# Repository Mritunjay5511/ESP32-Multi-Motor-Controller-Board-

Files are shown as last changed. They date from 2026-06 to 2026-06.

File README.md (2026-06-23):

# ESP32-Multi-Motor-Controller-Board-
Custom ESP32-WROOM-32 robotics controller PCB with onboard buck/LDO power regulation, auto-program circuit, and BTS7960/RMCS/relay/servo interfaces. Designed in KiCad.
# ESP32 Dual BTS7960 Motor Driver Breakout Board

A custom 2-layer PCB designed to handle heavy-duty robotics applications. It acts as a central control board breaking out an ESP32 to interface with dual BTS7960 motor drivers, an RMCS driver, and features onboard power regulation.

## Features
- **Microcontroller:** ESP32-WROOM-32
- **Power Stage:** LM2596 Buck Regulator (12v to 5v switching) & AMS1117-3.3 (5v to 3.3v switching)
- **Motor Control Interfaces:** 2x BTS7960 H-Bridge Drivers, 1x RMCS Driver interface
- **Peripherals:** Integrated Micro USB for programming (CH340C), Boot & Reset tactile switches, and broken-out GPIO headers.

## Design Highlights
- Optimized high-frequency switching loops for the buck regulator to minimize EMI.
- Completely isolated RF antenna keepout zone on both layers for maximum wireless signal integrity.
- Solid ground planes on both layers for optimal return paths.





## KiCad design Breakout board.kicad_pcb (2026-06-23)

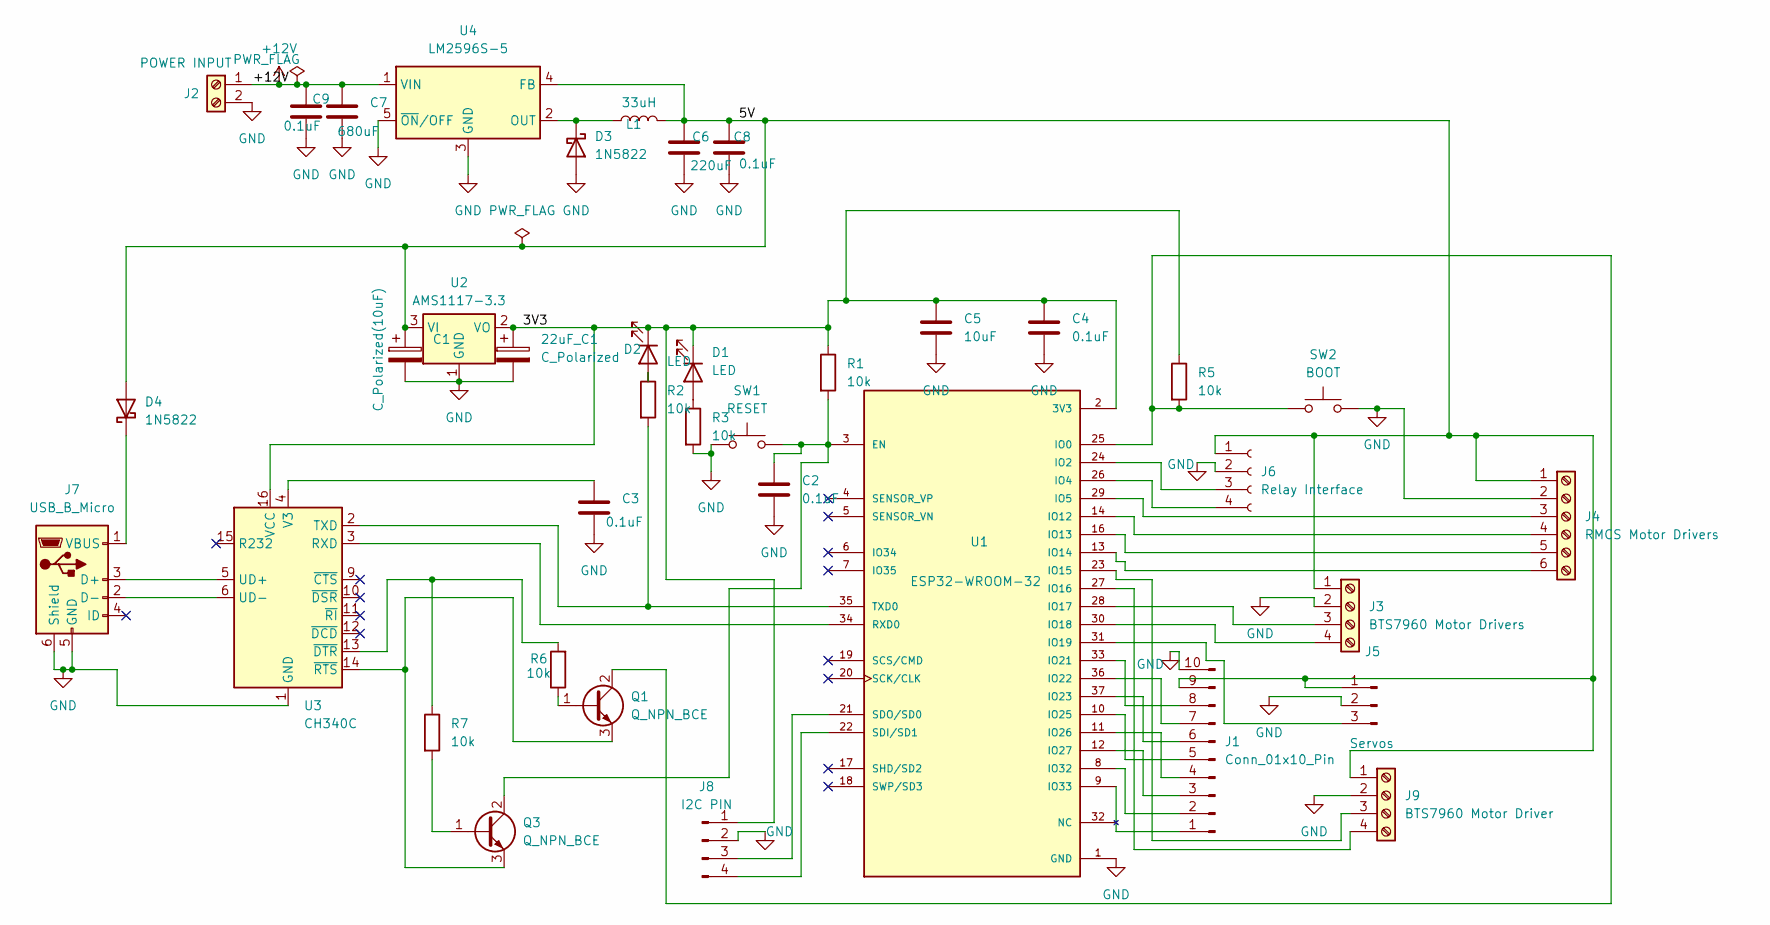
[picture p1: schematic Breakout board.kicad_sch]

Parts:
22uF_C1: C_Polarized; CP_Elec_4x5.4
C1: C_Polarized(10uF); CP_Elec_4x5.4
C2, C3, C4, C8, C9: 0.1uF; C_1206_3216Metric
C5: 10uF; C_1206_3216Metric
C6: 220uF; C_1206_3216Metric
C7: 680uF; C_1206_3216Metric
D1, D2: LED; LED_1206_3216Metric
D3: 1N5822; D_DO-201AD_P12.70mm_Horizontal
D4: 1N5822; D_DO-201AD_P15.24mm_Horizontal
J1: Conn_01x10_Pin; PinHeader_1x10_P2.54mm_Vertical
J2: POWER INPUT; TerminalBlock_Phoenix_MKDS-1,5-2-5.08_1x02_P5.08mm_Horizont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
J3: BTS7960 Motor Drivers; TerminalBlock_Phoenix_MKDS-1,5-4-5.08_1x04_P5.08mm_Horizont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
J4: RMCS Motor Drivers; TerminalBlock_Phoenix_MKDS-1,5-6-5.08_1x06_P5.08mm_Horizont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
J5: Servos; PinHeader_1x03_P2.54mm_Vertical
J6: Relay Interface; PinSocket_1x04_P2.54mm_Vertical
J7: USB_B_Micro; USB_Micro-B_Molex-105017-0001
J8: I2C PIN; PinHeader_1x04_P2.54mm_Vertical
J9: BTS7960 Motor Driver; TerminalBlock_Phoenix_MKDS-1,5-4-5.08_1x04_P5.08mm_Horizont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
L1: 33uH; L_1206_3216Metric
Q1, Q3: Q_NPN_BCE; SOT-23
R1, R2, R3, R5, R6, R7: 10k; R_1206_3216Metric
SW1: RESET; SW_PUSH_6mm
SW2: BOOT; SW_PUSH_6mm
U1: ESP32-WROOM-32; MODULE_ESP32-WROOM-32; PARTREV 2.9
U2: AMS1117-3.3; SOT-223-3_TabPin2
U3: CH340C; SOIC-16_3.9x9.9mm_P1.27mm
U4: LM2596S-5; TO-263-5_TabPin3

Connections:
+12V: C7.1, C9.1, J2.1, U4.1 (VIN)
/3V3: 22uF_C1.1, C4.1, C5.1, D1.1 (K), D2.1 (K), J8.1, R1.1, R5.1, U1.2 (3V3), U2.2 (VO), U3.16 (VCC)
/5V: C1.1, C6.1, C8.1, D4.2 (A), J1.9, J3.1, J4.1, J5.1, J6.1, J9.1, L1.2, U2.3 (VI), U4.4 (FB)
GND: 22uF_C1.2, C1.2, C2.2, C3.2, C4.2, C5.2, C6.2, C7.2, C8.2, C9.2, D3.2 (A), J1.10, J2.2, J3.2, J4.2, J5.2, J6.2, J7.5 (GND), J7.6 (Shield), J8.2, J9.2, R3.2, SW1.1, SW2.2, U1.1 (GND), U1.15 (GND), U1.38 (GND), U1.39_1 (GND), U1.39_2 (GND), U1.39_3 (GND), U1.39_4 (GND), U1.39_5 (GND), U1.39_6 (GND), U1.39_7 (GND), U1.39_8 (GND), U1.39_9 (GND), U1.39_10 (GND), U1.39_11 (GND), U1.39_12 (GND), U1.39_13 (GND), U1.39_14 (GND), U1.39_15 (GND), U1.39_16 (GND), U1.39_17 (GND), U1.39_18 (GND), U1.39_19 (GND), U1.39_20 (GND), U1.39_21 (GND), U2.1 (GND), U3.1 (GND), U4.3 (GND), U4.5 (~ON/OFF)
unnamed: D1.2 (A), R3.1
unnamed: D2.2 (A), R2.1
unnamed: D3.1 (K), L1.1, U4.2 (OUT)
unnamed: D4.1 (K), J7.1 (VBUS)
unnamed: J1.1, U1.9 (IO33)
unnamed: J1.2, U1.8 (IO32)
unnamed: J1.3, U1.12 (IO27)
unnamed: J1.4, U1.11 (IO26)
unnamed: J1.5, U1.10 (IO25)
unnamed: J1.6, U1.37 (IO23)
unnamed: J1.7, U1.36 (IO22)
unnamed: J1.8, U1.33 (IO21)
unnamed: J3.3, U1.28 (IO17)
unnamed: J3.4, U1.30 (IO18)
unnamed: J4.3, U1.29 (IO5)
unnamed: J4.4, U1.14 (IO12)
unnamed: J4.5, U1.16 (IO13)
unnamed: J4.6, U1.13 (IO14)
unnamed: J5.3, U1.31 (IO19)
unnamed: J6.3, U1.24 (IO2)
unnamed: J6.4, U1.26 (IO4)
unnamed: J7.3 (D+), U3.5 (UD+)
unnamed: J7.2 (D-), U3.6 (UD-)
unnamed: J8.3, U1.21 (SDO/SD0)
unnamed: J8.4, U1.22 (SDI/SD1)
unnamed: J9.3, U1.23 (IO15)
unnamed: J9.4, U1.27 (IO16)
unnamed: Q1.1 (B), R6.1
unnamed: Q1.2 (C), R5.2, SW2.1, U1.25 (IO0)
unnamed: Q1.3 (E), Q3.3 (E), U3.14 (~RTS)
unnamed: Q3.1 (B), R7.2
unnamed: C2.1, Q3.2 (C), R1.2, SW1.2, U1.3 (EN)
unnamed: U1.34 (RXD0), U3.3 (RXD)
unnamed: R2.2, U1.35 (TXD0), U3.2 (TXD)
unnamed: C3.1, U3.4 (V3)
unnamed: R6.2, R7.1, U3.13 (~DTR)

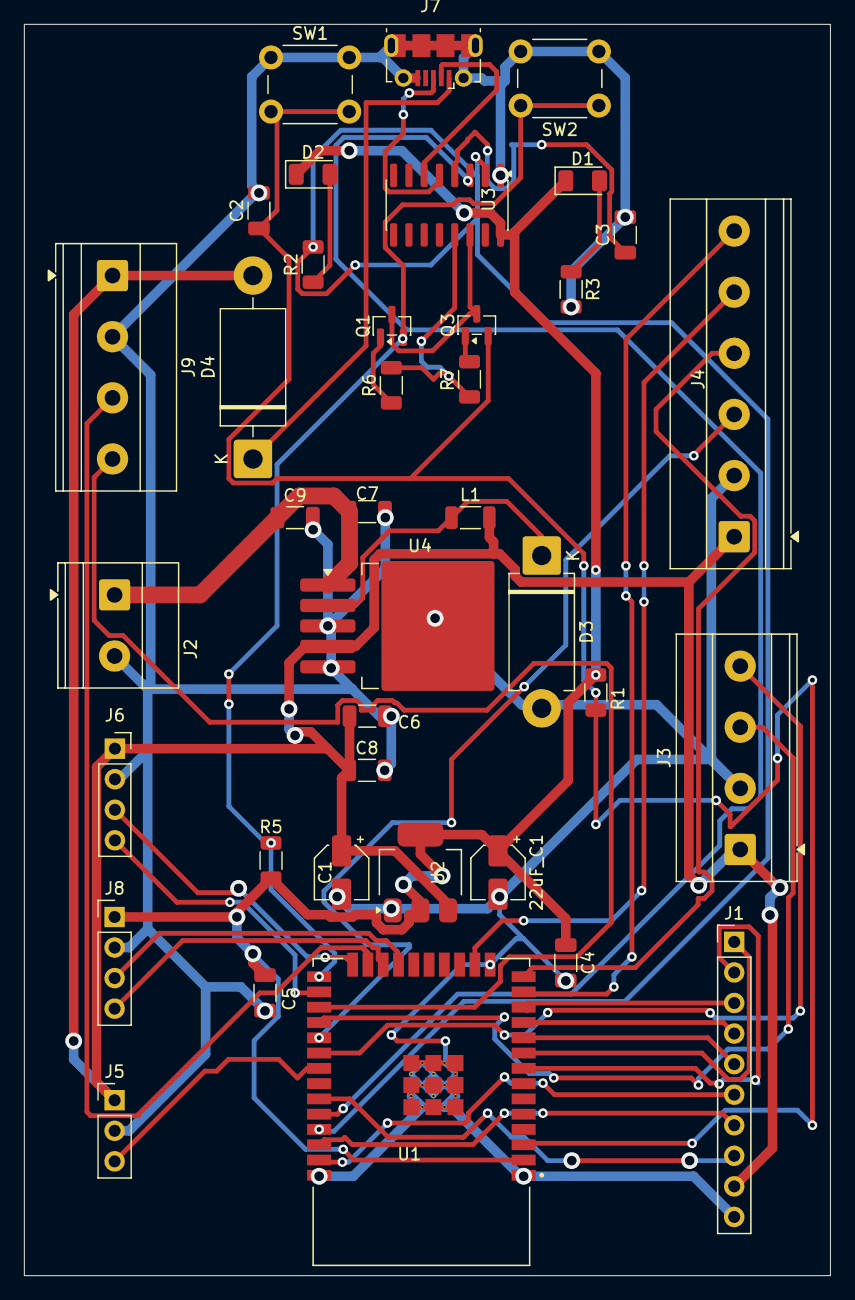
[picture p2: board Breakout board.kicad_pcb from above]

Board: 2 copper layers, 67.0 x 104.0 mm, 38 parts (0 on the bottom side), 40 nets.
